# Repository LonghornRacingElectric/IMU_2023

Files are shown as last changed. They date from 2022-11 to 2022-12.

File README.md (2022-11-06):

# IMU Board
### ver. 2023
The hardware board containing the inertial measurement unit (IMU)

A screenshot of the IMU schematic

## Purpose
This board logs 6-axis accelerometer and gyroscope data and sends that data across the attached CAN bus.

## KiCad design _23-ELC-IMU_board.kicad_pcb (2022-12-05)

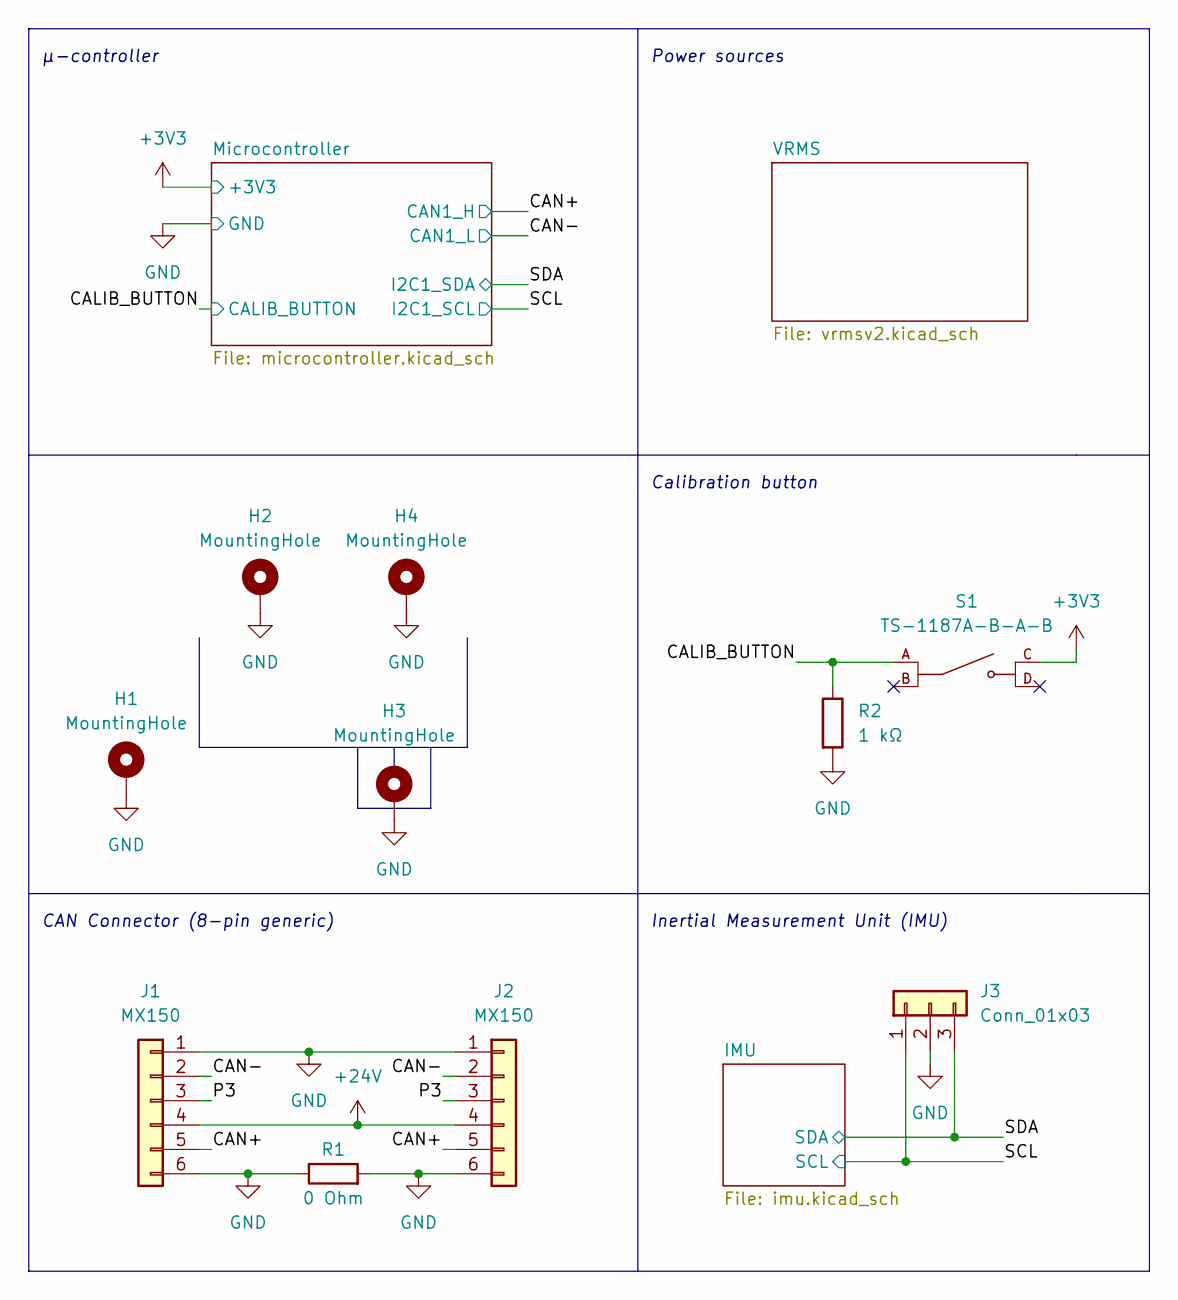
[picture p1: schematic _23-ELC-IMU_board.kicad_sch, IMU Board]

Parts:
H1, H2, H3, H4: MountingHole; MountingHole_3.5mm_Pad
J1, J2: MX150; Molex_Micro-Fit_3.0_43045-0600_2x03_P3.00mm_Horizontal
J3: Conn_01x03; PinHeader_1x03_P1.27mm_Vertical
R1: 0 Ohm; R_0603_1608Metric_Pad0.98x0.95mm_HandSolder
R2: 1 kΩ; R_0603_1608Metric_Pad0.98x0.95mm_HandSolder
S1: TS-1187A-B-A-B; SW_TS-1187A-B-A-B; PARTREV A0

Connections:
+3V3: S1.C; also elsewhere on the board
+24V: J1.4, J2.4; also elsewhere on the board
/CALIB_BUTTON: R2.1, S1.A; also elsewhere on the board
/CAN+: J1.5, J2.5; also elsewhere on the board
/CAN-: J1.2, J2.2; also elsewhere on the board
/P3: J1.3, J2.3
/SCL: J3.1; also elsewhere on the board
/SDA: J3.3; also elsewhere on the board
GND: H1.1, H2.1, H3.1, H4.1, J1.1, J1.6, J2.1, J2.6, J3.2, R1.1, R1.2, R2.2; also elsewhere on the board

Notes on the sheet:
Power sources
µ-controller
Calibration button
Inertial Measurement Unit (IMU)
CAN Connector (8-pin generic)

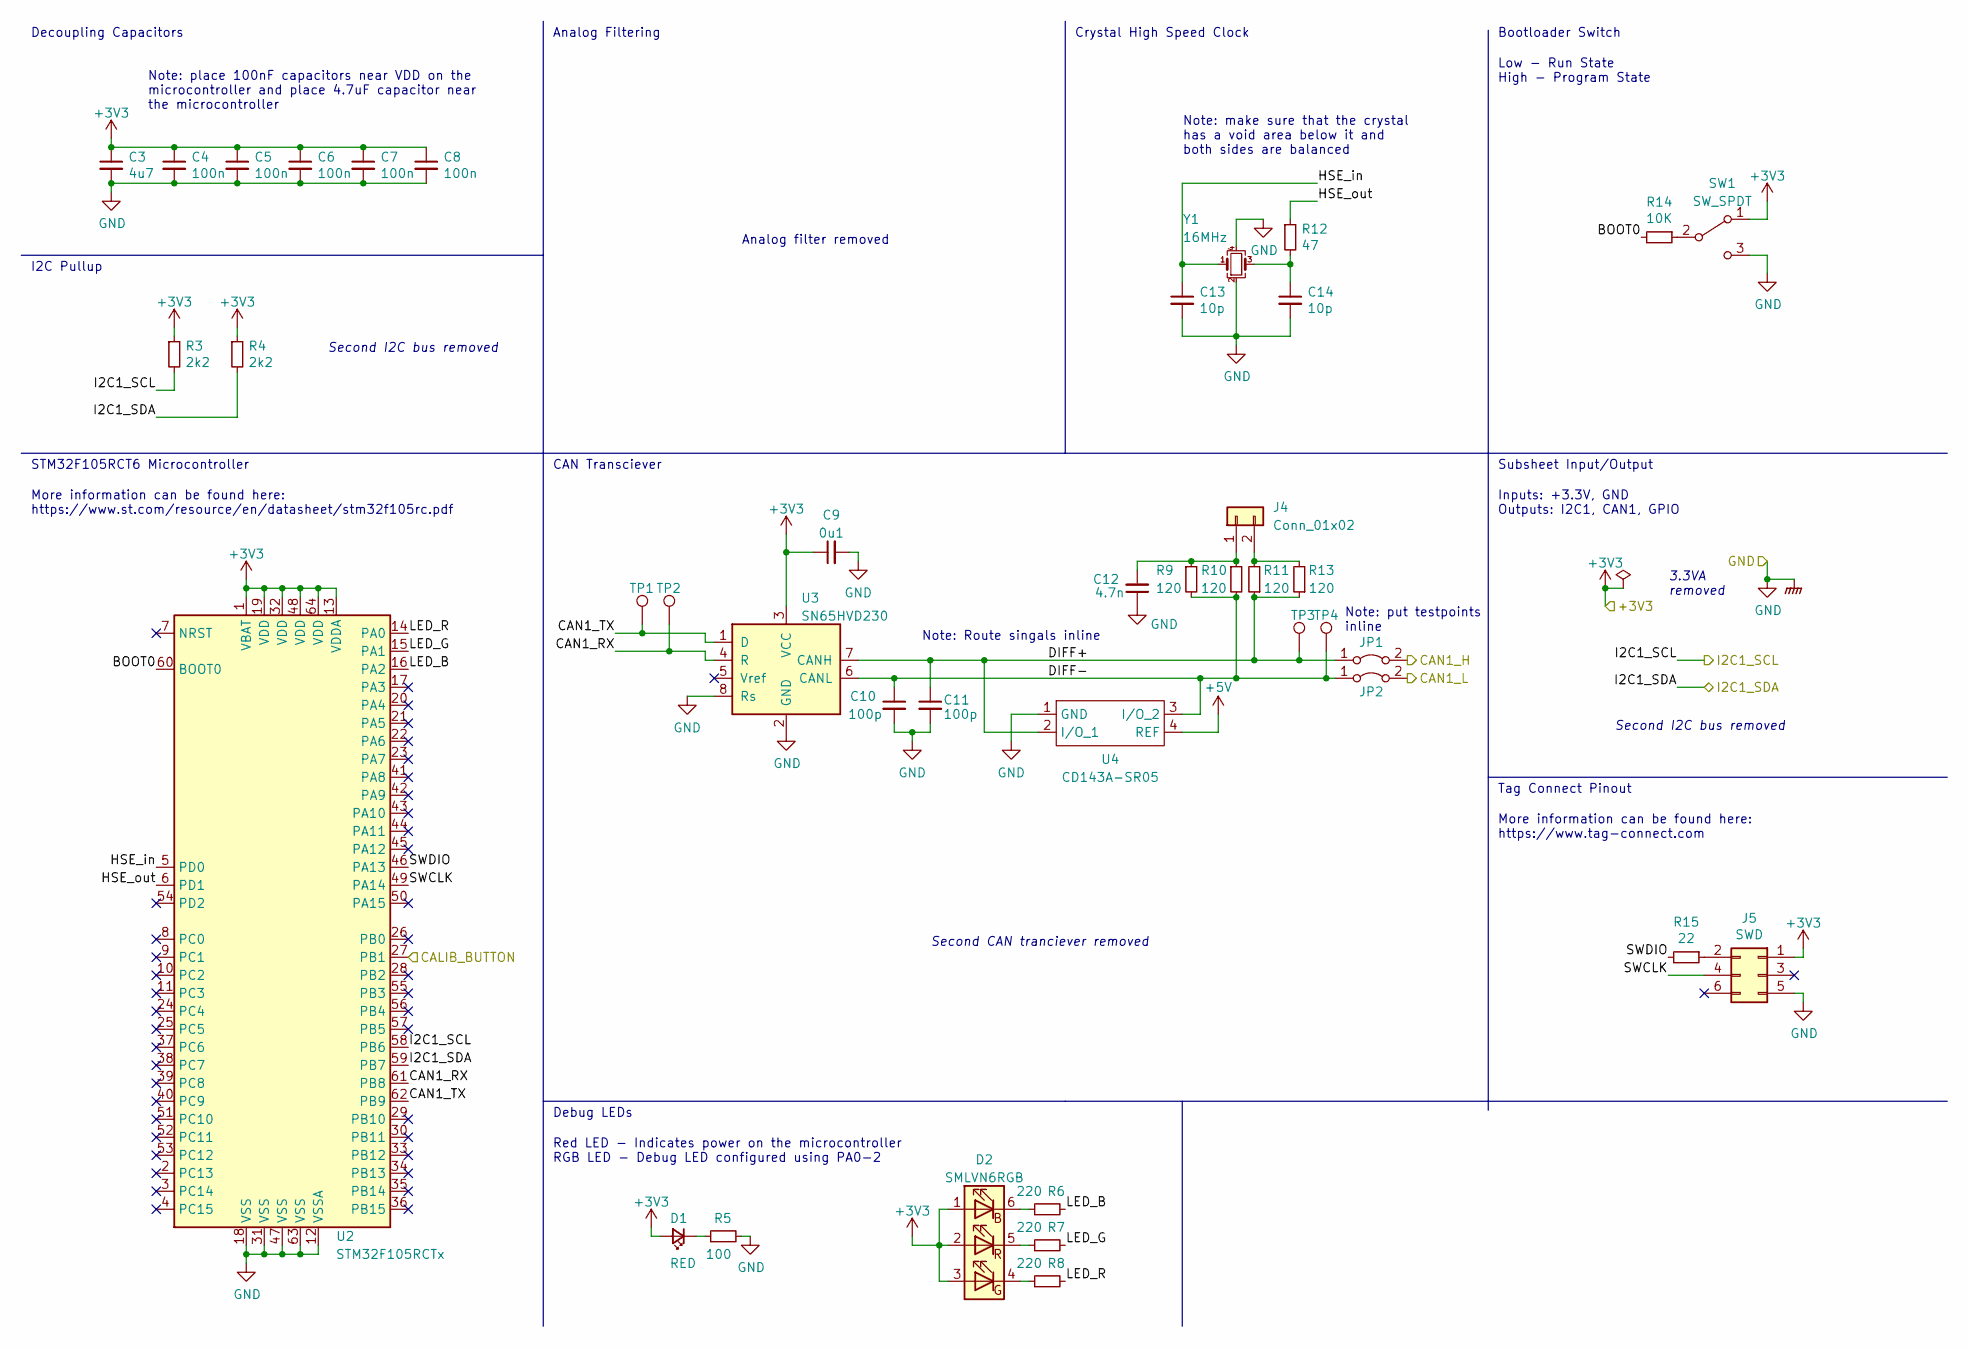
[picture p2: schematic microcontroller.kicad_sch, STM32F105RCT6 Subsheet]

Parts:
C3: 4u7; C_0603_1608Metric_Pad1.08x0.95mm_HandSolder
C4, C5, C6, C7, C8: 100n; C_0603_1608Metric_Pad1.08x0.95mm_HandSolder
C9: 0u1; C_0603_1608Metric_Pad1.08x0.95mm_HandSolder
C10, C11: 100p; C_0603_1608Metric_Pad1.08x0.95mm_HandSolder
C12: 4.7n; C_0603_1608Metric_Pad1.08x0.95mm_HandSolder
C13, C14: 10p; C_0603_1608Metric_Pad1.08x0.95mm_HandSolder
D1: RED; LED_0603_1608Metric_Pad1.05x0.95mm_HandSolder
D2: SMLVN6RGB; LED_ROHM_SMLVN6
J4: Conn_01x02; PinHeader_1x02_P2.54mm_Vertical
J5: SWD; PinHeader_2x03_P1.27mm_Vertical
JP1, JP2: SolderJumper-2_P1.3mm_Bridged2Bar_Pad1.0x1.5mm
R3, R4: 2k2; R_0603_1608Metric_Pad0.98x0.95mm_HandSolder
R5: 100; R_0603_1608Metric_Pad0.98x0.95mm_HandSolder
R6, R7, R8: 220; R_0603_1608Metric_Pad0.98x0.95mm_HandSolder
R9, R10, R11, R13: 120; R_0603_1608Metric_Pad0.98x0.95mm_HandSolder
R12: 47; R_0603_1608Metric_Pad0.98x0.95mm_HandSolder
R14: 10K; R_0603_1608Metric_Pad0.98x0.95mm_HandSolder
R15: 22; R_0603_1608Metric_Pad0.98x0.95mm_HandSolder
SW1: SW_SPDT; PinHeader_1x03_P1.27mm_Vertical
TP1, TP2, TP3, TP4: TestPoint_THTPad_1.0x1.0mm_Drill0.5mm
U2: STM32F105RCTx; LQFP-64_10x10mm_P0.5mm
U3: SN65HVD230; SOIC-8_3.9x4.9mm_P1.27mm
U4: CD143A-SR05; CD143ASR05
Y1: 16MHz; Crystal_SMD_3225-4Pin_3.2x2.5mm

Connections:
+3V3: C3.1, C4.1, C5.1, C6.1, C7.1, C8.1, C9.1, D1.2 (A), D2.1 (BA), D2.2 (RA), D2.3 (GA), J5.1, R3.1, R4.1, SW1.1 (A), U2.1 (VBAT), U2.13 (VDDA), U2.19 (VDD), U2.32 (VDD), U2.48 (VDD), U2.64 (VDD), U3.3 (VCC); also elsewhere on the board
+5V: U4.4 (REF); also elsewhere on the board
/CALIB_BUTTON: U2.27 (PB1); also elsewhere on the board
/CAN+: JP1.2 (B); also elsewhere on the board
/CAN-: JP2.2 (B); also elsewhere on the board
/Microcontroller/BOOT0: R14.2, U2.60 (BOOT0)
/Microcontroller/CAN1_RX: TP2.1, U2.61 (PB8), U3.4 (R)
/Microcontroller/CAN1_TX: TP1.1, U2.62 (PB9), U3.1 (D)
/Microcontroller/DIFF+: C11.1, JP1.1 (A), R11.1, R13.1, TP3.1, U3.7 (CANH), U4.2 (I/O_1)
/Microcontroller/DIFF-: C10.1, JP2.1 (A), R9.2, R10.2, TP4.1, U3.6 (CANL), U4.3 (I/O_2)
/Microcontroller/HSE_in: C13.1, U2.5 (PD0), Y1.1
/Microcontroller/HSE_out: R12.1, U2.6 (PD1)
/Microcontroller/LED_B: R6.2, U2.16 (PA2)
/Microcontroller/LED_G: R7.2, U2.15 (PA1)
/Microcontroller/LED_R: R8.2, U2.14 (PA0)
/Microcontroller/SWCLK: J5.4, U2.49 (PA14)
/Microcontroller/SWDIO: R15.2, U2.46 (PA13)
/SCL: R3.2, U2.58 (PB6); also elsewhere on the board
/SDA: R4.2, U2.59 (PB7); also elsewhere on the board
GND: C3.2, C4.2, C5.2, C6.2, C7.2, C8.2, C9.2, C10.2, C11.2, C12.1, C13.2, C14.2, J5.5, R5.2, SW1.3 (C), U2.12 (VSSA), U2.18 (VSS), U2.31 (VSS), U2.47 (VSS), U2.63 (VSS), U3.2 (GND), U3.8 (Rs), U4.1 (GND), Y1.2, Y1.4; also elsewhere on the board
unnamed: C12.2, J4.1, R9.1, R10.1
unnamed: C14.1, R12.2, Y1.3
unnamed: D1.1 (K), R5.1
unnamed: D2.4 (GK), R8.1
unnamed: D2.5 (RK), R7.1
unnamed: D2.6 (BK), R6.1
unnamed: J4.2, R11.2, R13.2
unnamed: J5.2, R15.1
unnamed: R14.1, SW1.2 (B)

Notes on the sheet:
Note: place 100nF capacitors near VDD on the microcontroller and place 4.7uF capacitor near the microcontroller
Inputs: +3.3V, GND Outputs: I2C1, CAN1, GPIO
Bootloader Switch
Low - Run State High - Program State
Note: Route singals inline
Second I2C bus removed
Analog Filtering
I2C Pullup
Tag Connect Pinout
Analog filter removed
Subsheet Input/Output
Debug LEDs
3.3VA removed
Note: make sure that the crystal has a void area below it and both sides are balanced
Decoupling Capacitors
Crystal High Speed Clock
STM32F105RCT6 Microcontroller
CAN Transciever
More information can be found here: https://www.st.com/resource/en/datasheet/stm32f105rc.pdf
More information can be found here: https://www.tag-connect.com
Note: put testpoints inline
Second CAN tranciever removed
Red LED - Indicates power on the microcontroller RGB LED - Debug LED configured using PA0-2

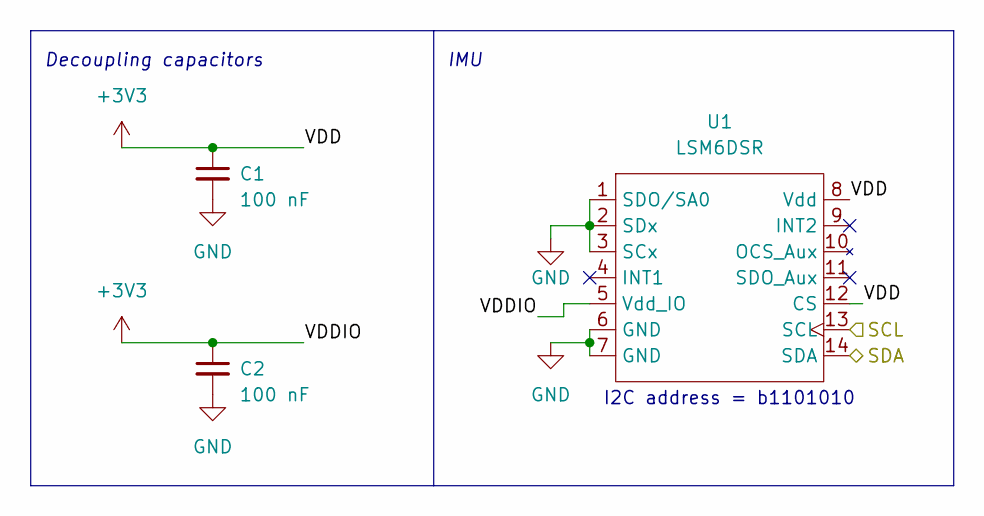
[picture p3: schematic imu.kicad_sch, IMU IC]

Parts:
C1, C2: 100 nF; C_0603_1608Metric_Pad1.08x0.95mm_HandSolder
U1: LSM6DSR; LGA-14L_3x2.5mm_P0.86mm

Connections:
+3V3: C1.1, C2.1, U1.5 (Vdd_IO), U1.8 (Vdd), U1.12 (CS); also elsewhere on the board
/SCL: U1.13 (SCL); also elsewhere on the board
/SDA: U1.14 (SDA); also elsewhere on the board
GND: C1.2, C2.2, U1.1 (SDO/SA0), U1.2 (SDx), U1.3 (SCx), U1.6 (GND), U1.7 (GND); also elsewhere on the board

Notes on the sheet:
IMU
Decoupling capacitors
I2C address = b1101010

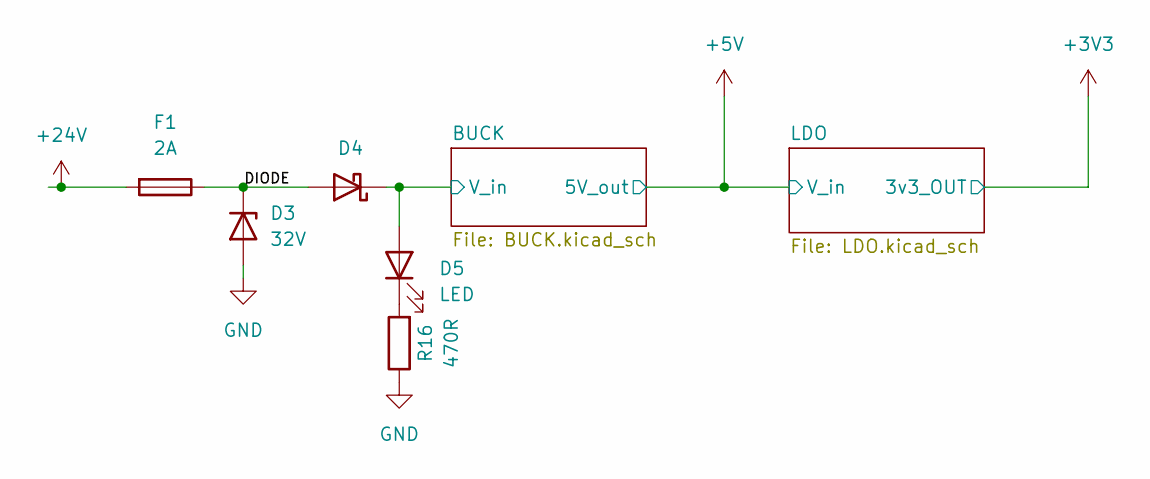
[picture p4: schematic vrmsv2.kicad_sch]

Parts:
D3: 32V; D_SOD-323_HandSoldering
D4: 0.7dV; D_SMA_Handsoldering
D5: LED; LED_0603_1608Metric_Pad1.05x0.95mm_HandSolder
F1: 2A; Fuse_1206_3216Metric_Pad1.42x1.75mm_HandSolder
R16: 470R; R_0603_1608Metric_Pad0.98x0.95mm_HandSolder

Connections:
+24V: F1.2; also elsewhere on the board
/VRMS/BUCK/V_in: D4.1 (K), D5.2 (A); also elsewhere on the board
/VRMS/DIODE: D3.1 (K), D4.2 (A), F1.1
GND: D3.2 (A), R16.1; also elsewhere on the board
unnamed: D5.1 (K), R16.2

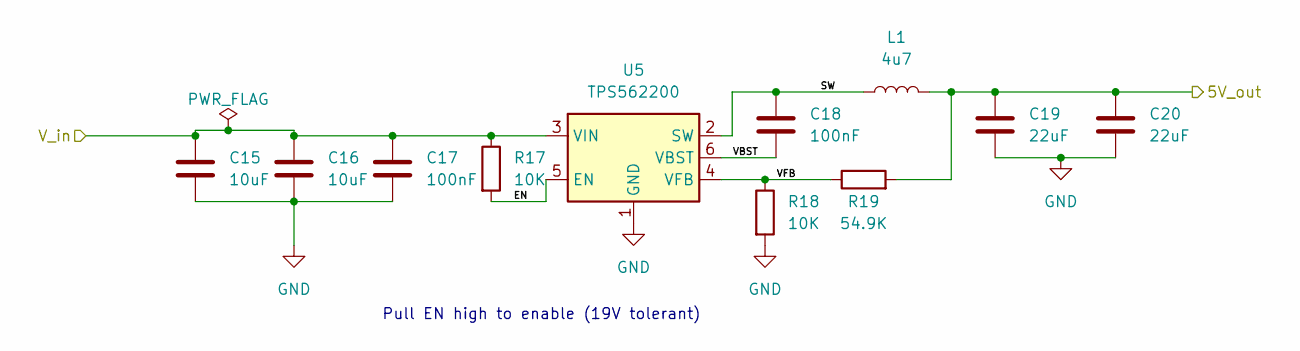
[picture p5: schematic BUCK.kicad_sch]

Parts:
C15, C16: 10uF; C_0603_1608Metric_Pad1.08x0.95mm_HandSolder
C17, C18: 100nF; C_0603_1608Metric_Pad1.08x0.95mm_HandSolder
C19, C20: 22uF; C_0603_1608Metric_Pad1.08x0.95mm_HandSolder
L1: 4u7; L_Sunlord_MWSA0518_5.4x5.2mm; Part # C408410
R17, R18: 10K; R_0603_1608Metric_Pad0.98x0.95mm_HandSolder
R19: 54.9K; R_0603_1608Metric_Pad0.98x0.95mm_HandSolder
U5: TPS562200; SOT-23-6

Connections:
+5V: C19.1, C20.1, L1.2, R19.2; also elsewhere on the board
/VRMS/BUCK/EN: R17.2, U5.5 (EN)
/VRMS/BUCK/SW: C18.1, L1.1, U5.2 (SW)
/VRMS/BUCK/VBST: C18.2, U5.6 (VBST)
/VRMS/BUCK/VFB: R18.1, R19.1, U5.4 (VFB)
/VRMS/BUCK/V_in: C15.1, C16.1, C17.1, R17.1, U5.3 (VIN); also elsewhere on the board
GND: C15.2, C16.2, C17.2, C19.2, C20.2, R18.2, U5.1 (GND); also elsewhere on the board

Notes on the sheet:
Pull EN high to enable (19V tolerant)

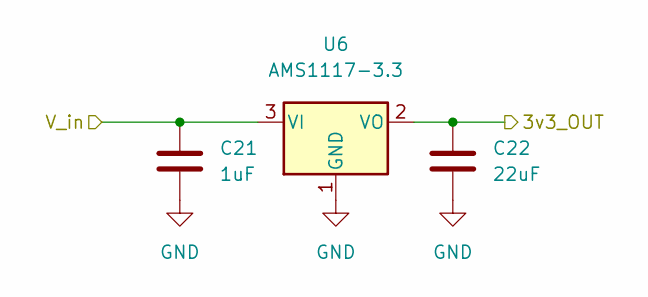
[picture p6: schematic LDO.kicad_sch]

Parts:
C21: 1uF; C_0603_1608Metric_Pad1.08x0.95mm_HandSolder
C22: 22uF; C_0603_1608Metric_Pad1.08x0.95mm_HandSolder
U6: AMS1117-3.3; SOT-223-3_TabPin2

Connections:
+3V3: C22.1, U6.2 (VO); also elsewhere on the board
+5V: C21.1, U6.3 (VI); also elsewhere on the board
GND: C21.2, C22.2, U6.1 (GND); also elsewhere on the board

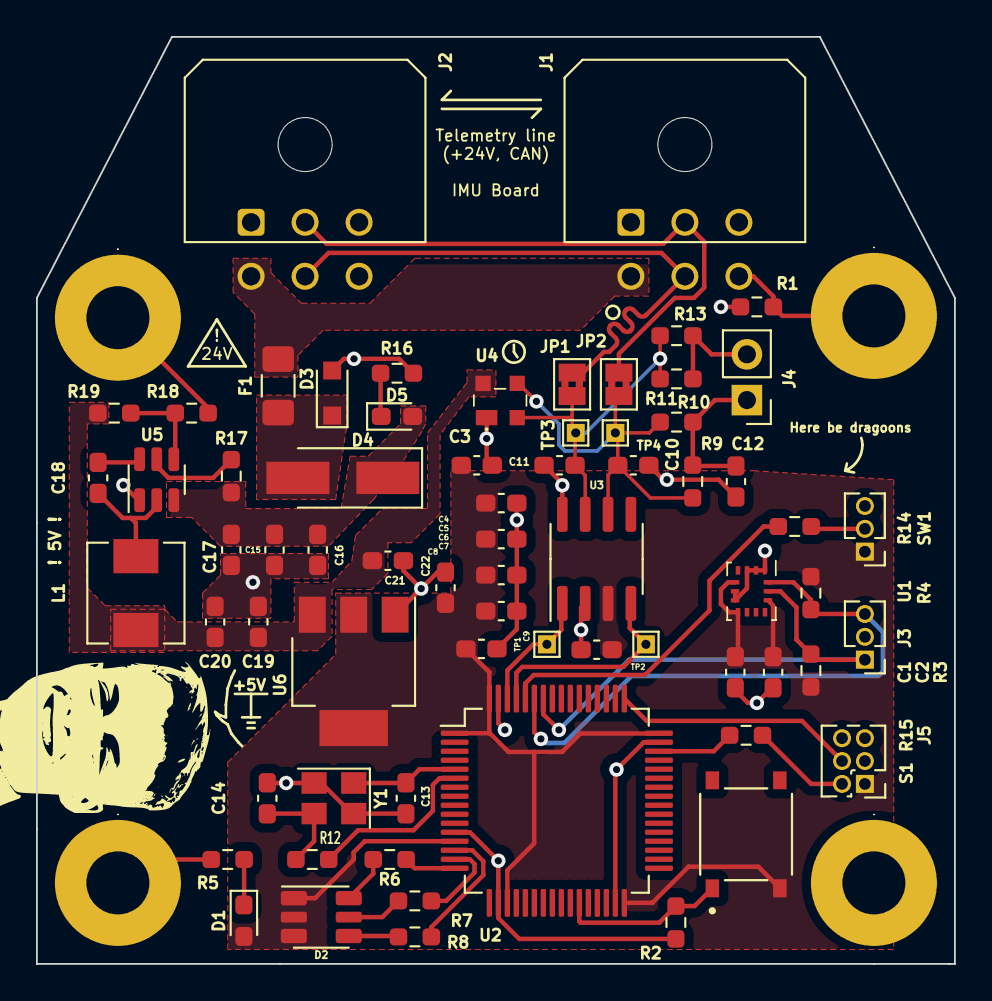
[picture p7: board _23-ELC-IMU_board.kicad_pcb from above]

Board: 2 copper layers, 51.0 x 51.5 mm, 72 parts (0 on the bottom side), 38 nets.

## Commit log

2022-11-06 Initial commit
    Passed initial subteam review woot woot
    [BUCK.kicad_sch, LDO.kicad_sch, _23-ELC-IMU_board.kicad_pcb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]
2022-11-06 Minor schematic graphics change
    Just changing some things and making KiCAD create a local backup to make sure the .gitignore functions
    [_23-ELC-IMU_board.kicad_sch]
2022-11-06 Added test points for I2C
    [_23-ELC-IMU_board.kicad_sch]
2022-11-06 100 ohm => 1 kOhm
    Pull down probably too low
    [_23-ELC-IMU_board.kicad_sch]
2022-11-06 Updated subsheets
    [BUCK.kicad_sch, LDO.kicad_sch, _23-ELC-IMU_board.kicad_sch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]
2022-11-06 Adjusted CAN bus voltage to 5V
    [_23-ELC-IMU_board.kicad_sch, microcontroller.kicad_sch]
2022-11-13 Added three mounting holes
    I have no idea what to do here
    [_23-ELC-IMU_board.kicad_sch]
2022-11-13 Pushing assorted changes
    I think I just changed a couple names
    [_23-ELC-IMU_board.kicad_sch]
2022-11-13 Updated (?) subsheets
    [BUCK.kicad_sch, LDO.kicad_sch, _23-ELC-IMU_board.kicad_sch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]
2022-11-15 Changed connector to 1x6
    Will be using Deutsch DT-6
    [BUCK.kicad_sch, _23-ELC-IMU_board.kicad_sch]
2022-11-15 Added 3x1 connector for logical analyzer
    Idk how to denote a 3-pin header
    [_23-ELC-IMU_board.kicad_sch]
2022-11-27 Removed analog filtering
    There are no analog parts in this PCB
    [_23-ELC-IMU_board.kicad_sch, microcontroller.kicad_sch]
2022-11-27 Annotated schematic
    [BUCK.kicad_sch, LDO.kicad_sch, _23-ELC-IMU_board.kicad_sch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]
2022-11-27 Added DT connector footprints and began layout
    [_23-ELC-IMU_board.kicad_sch, imu.kicad_sch]
2022-12-04 Redo of placement
    Really like this attempt
    [_23-ELC-IMU_board.kicad_pcb, _23-ELC-IMU_board.kicad_sch, imu.kicad_sch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]
2022-12-04 Started drawing like 496130 areas
    [_23-ELC-IMU_board.kicad_pcb]
2022-12-04 All pours done
    [_23-ELC-IMU_board.kicad_pcb]
2022-12-05 I am happy with this layout
    [_23-ELC-IMU_board.kicad_pcb]
2022-12-05 Added 0 Ohm resistor between shield (grounded)
    [BUCK.kicad_sch, LDO.kicad_sch, _23-ELC-IMU_board.kicad_pcb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]
2022-12-05 Connected final things for this iteration of the board
    [_23-ELC-IMU_board.kicad_pcb]
